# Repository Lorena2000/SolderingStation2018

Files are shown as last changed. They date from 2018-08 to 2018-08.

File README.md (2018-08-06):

# SolderingStation2018

I’m an apprentice who works in Switzerland and tried to build the soldering station. 
Unfortunatly it doesen't worked, and i had made some changes. 
I like to offer you the changes that not everyone has to find out them by themself. 

At first the Arduino pro mini with the correct pin assignment couldn’t be delivered, it
was an old version and the companies who sold them, doesn’t deliver anything to
Switzerland. So I draw a new eagle file, I just changed the Arduino mini with
an Arduino Nano. Later when everything worked I made some more changes, the
reset wasn’t connected, added a GND connection and change the connection of the
Potentiometer. 

I found the correct display for the station but the program doesn’t work on the new Arduino
version (1.8.5). But the display needs the new version to work, so I debugged
the program with help from an informatics student. 

Because I changed the Arduino and some other components I also had to change the 3D
components, but with the new version of Inventor I couldn’t import the stl.
files so I draw new ones. 

You could find the Programm, the New Stl. files, the new Arduino board with the shema and a partlist.

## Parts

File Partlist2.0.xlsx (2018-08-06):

Soldering station 2018
I'm sorry that some names are in German that's because I order them in German and wanted to be sure you found the right elements.
If you don’t understand it, just search for the articles on conrad.ch and then translate the website to English.
I just wrote where i found the articles, perhaps you found them somewere cheaper.
What | How many | Information | Where I have order it | Specificat information | Remark
Arduino Nano | 1 |  | Arduino.cc | https://store.arduino.cc/usa/arduino-nano
Potentiometer | 1 |  | conrad | Dreh Potentiometer Mono 0.25 W 10 kΩ | Artikel Nr. 9605
Switch | 1 |  | conrad | Wippschalter 12 V/DC 20 A | Artikel Nr. 700749Kfz
Power Supply | 1 |  | conrad | USB Ladegerät Goobay | Artikel Nr. 1602854 62
display | 1
OPA336U | 1 |  | Distrelec | Operationsverstärker zweifach 0.1 MHz | Artikel Nr. 30022737
78L05F | 1 |  | Distrelec | Linearer Spannungsregler 5 V SOT-89-3, | Artikel Nr. 30018604
BSN20 | 2 |  | Distrelec | Kleinleistungstransistor SOT-23 N 50 V | Artikel Nr. 17101930
IRF7416 | 1 |  | conrad | MOSFET Infineon Technologies | Artikel Nr. IRF7416PBF
Power_JACKPTH | 1 |  | conrad | Niedervolt Steckverbinder Buchse | Artikel Nr. 735742
Klinkenbuchse ø 3.5 mm | 1 |  | conrad | Klinken Steckverbinder 3.5 mm Buchse | Artikel Nr. 734101
Soldering Iron | 1 |  | conrad | Lötspitze Nadelform Weller RT1 Spitzen Größe 0.2 mm | cost ca. 50 CHF
Klinken Steckverbinder 3.5 mm Buchse | 1 |  | conrad | KlinkenSteckverbinder 3.5 mm Stecker | Artikel Nr. NYS 231
Klinken-Steckverbinder 3.5 mm Stecker | 1 |  | conrad | Klinken Steckverbinder 3.5 mm Buchse | Artikel Nr. 595223
Mikrofonkabel 2 x 0.50 mm² | 3 m |  | conrad | Mikrofonkabel 2 x 0.50 mm² Schwarz LappKabel | Artikel Nr. 49900153
Resistor | 1 | 1MΩ | This was available in a intern lager at the company I worked for. | Form of structur 0603
Resistor | 10 | 1kΩ | " | "
Resistor | 1 | 100Ω | " | "
Resistor | 3 | 10kΩ | " | "
Resistor | 1 | 56kΩ | " | "
capacitor | 5 | 100nF | " | "
capacitor | 1 | 10µF 6V | " | "
capacitor | 1 | 10µF 16V | " | "
 |  |  | Written by Lorena Lötscher

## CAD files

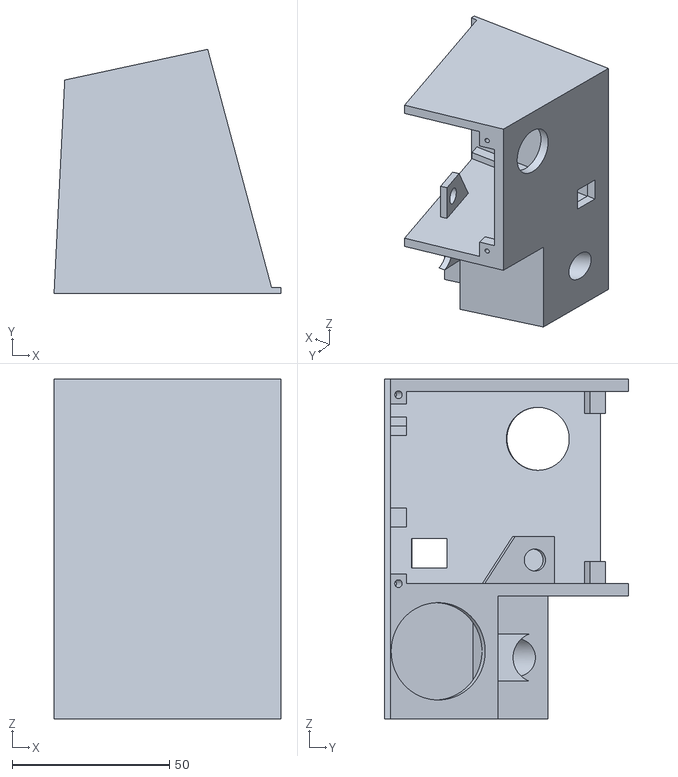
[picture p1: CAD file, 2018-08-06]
3D-Elements/stl-files/SolderingStation.stl
72.1 x 77.6 x 108.0

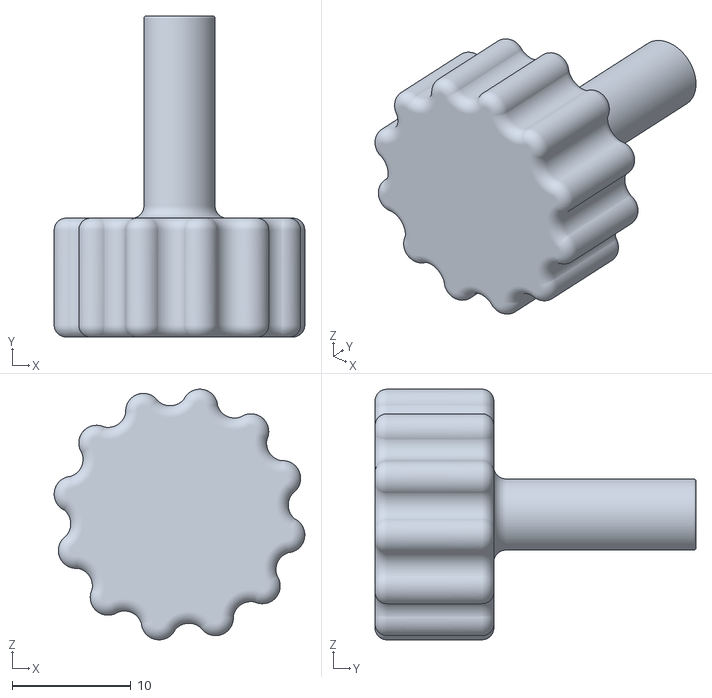
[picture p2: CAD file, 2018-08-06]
3D-Elements/stl-files/Botton.stl
21.1 x 27.0 x 21.1

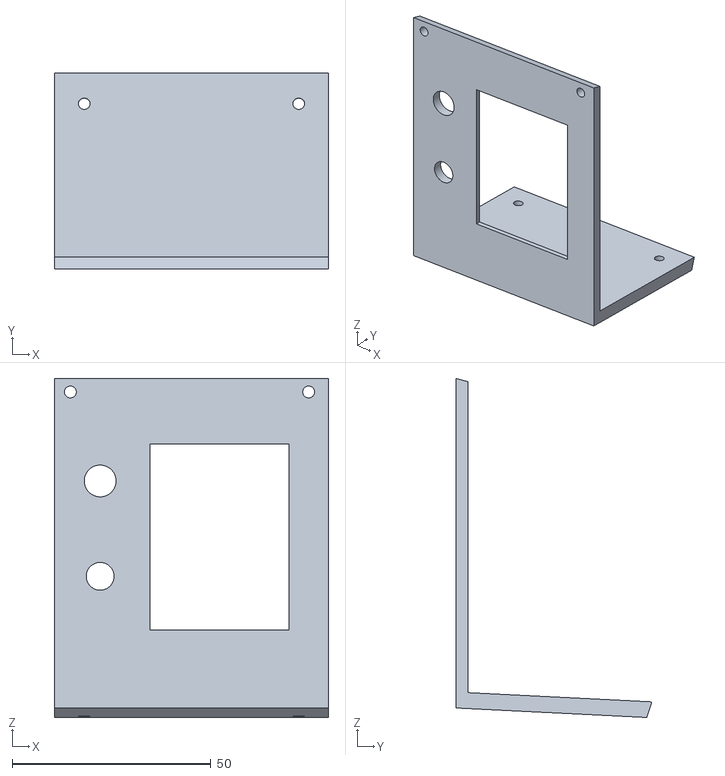
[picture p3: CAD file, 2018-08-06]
3D-Elements/stl-files/Top.stl
69.0 x 49.3 x 85.4

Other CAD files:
3D-Elements/Button.ipt
3D-Elements/SolderingStation.iam
3D-Elements/SolderingStation.ipt
3D-Elements/Top.ipt

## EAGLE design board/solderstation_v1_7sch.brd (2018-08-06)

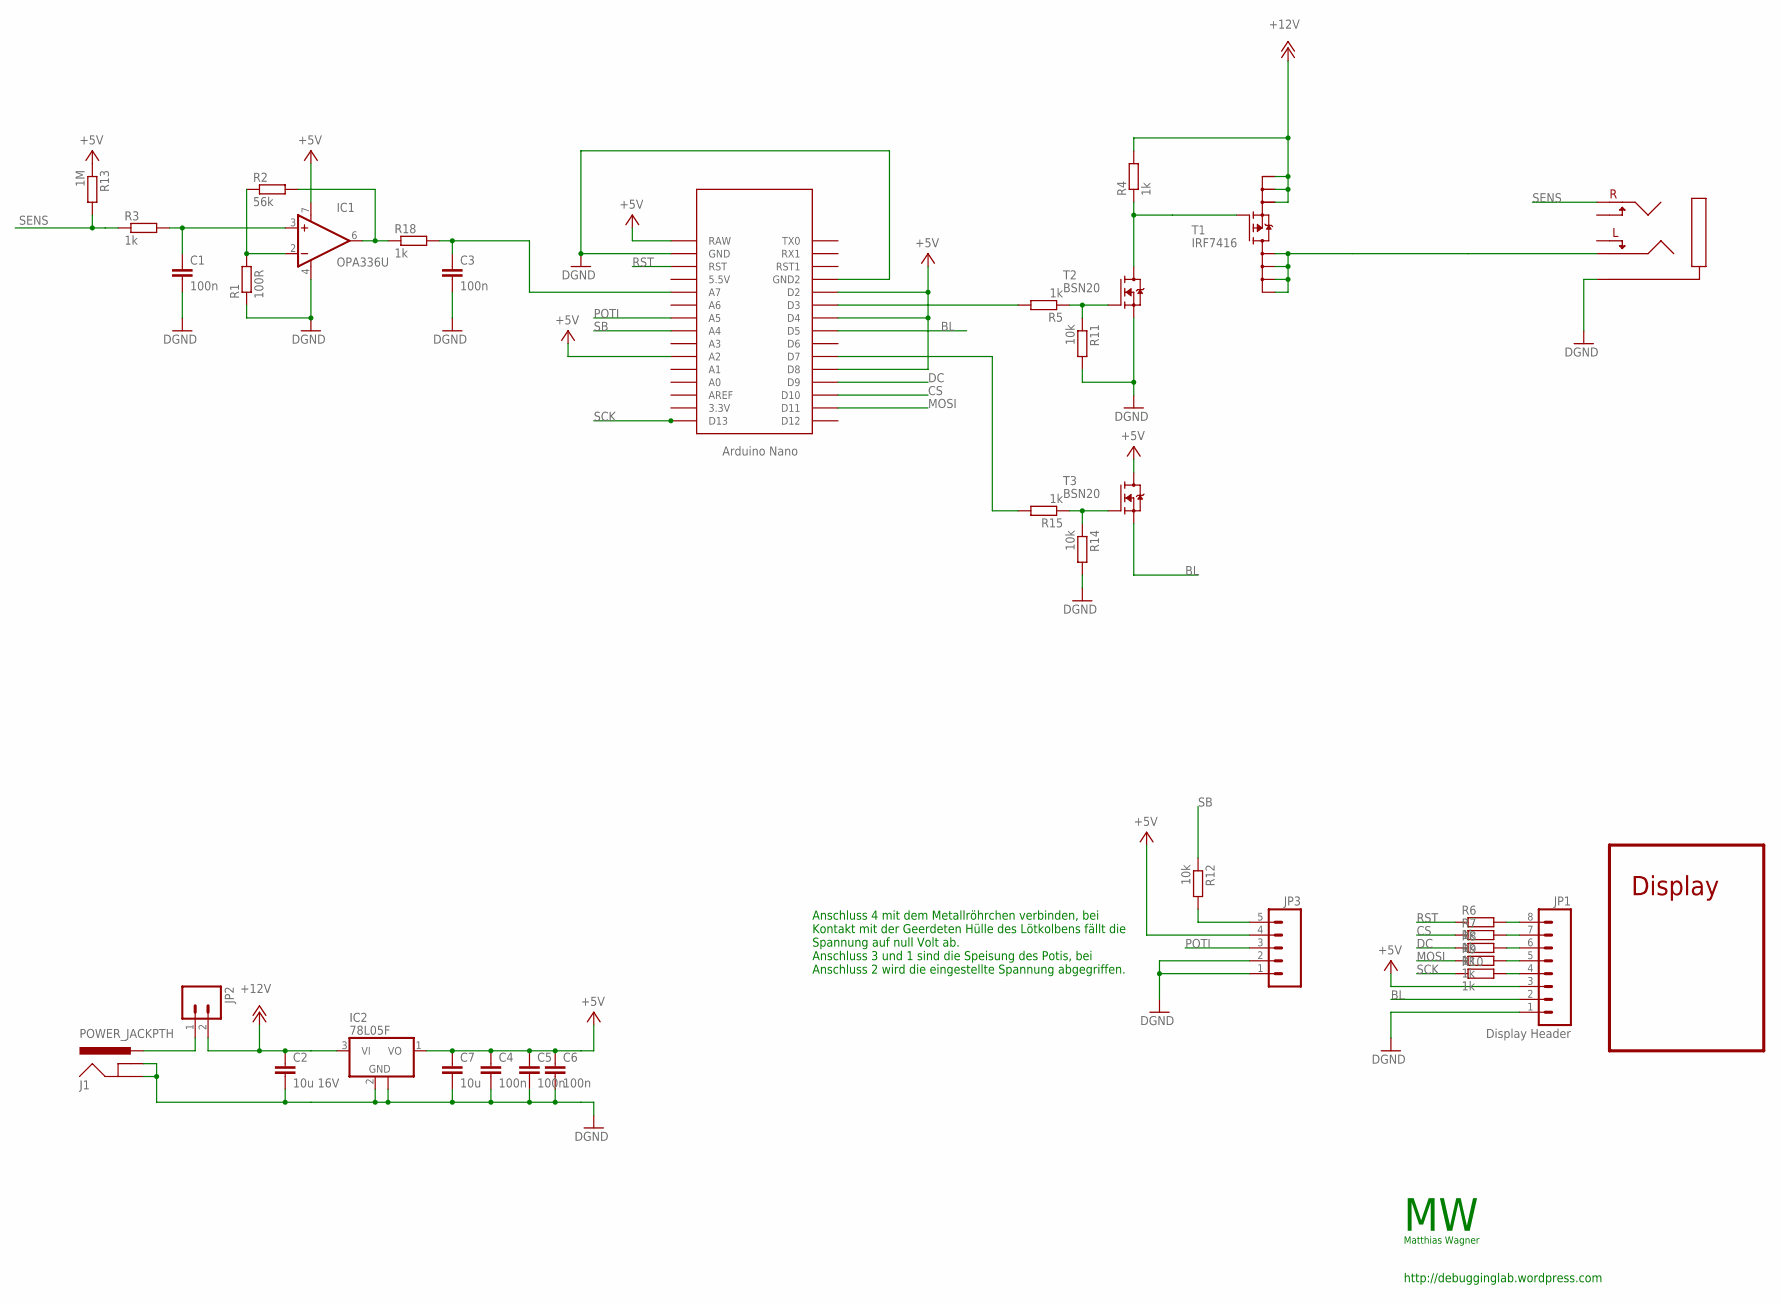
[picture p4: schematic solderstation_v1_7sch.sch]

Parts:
C1, C3, C4, C5, C6: 100n; C0603
C2: 10u 16V; C1206
C7: 10u; C1206
IC1: OPA336U; SO08
IC2: 78L05F; SOT89
J1: POWER_JACKPTH; POWER_JACK_PTH
JP1: Display Header; 1X08_LOCK
JP2: M02LOCK_LONGPADS; 1X02_LOCK_LONGPADS
JP3: M05; 05P
R1: 100R; R0603
R2: 56k; R0603
R3, R4, R5, R6, R7, R8, R9, R10, R15, R18: 1k; R0603
R11, R12, R14: 10k; R0603
R13: 1M; R0603
T1: IRF7416; SO8
T2, T3: BSN20; SOT23
U$1: NANO
U$2: AUDIO_JACK_3,5MMCONRAD; AUDIO_JACK_3,5MM_CONRAD

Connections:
+5V: C4.1, C5.1, C6.1, C7.1, IC1.7 (V+), IC2.1 (VO), JP1.3, JP3.4, R13.1, T3.3 (D), U$1.A2, U$1.D2, U$1.D4, U$1.D8, U$1.RAW
+12V: C2.1, IC2.3 (VI), JP2.2, R4.2, T1.1 (S0), T1.2 (S1), T1.3 (S2)
BL: JP1.2, T3.2 (S), U$1.D5
CS: R7.1, U$1.D10
DC: R8.1, U$1.D9
DGND: C1.2, C2.2, C3.2, C4.2, C5.2, C6.2, C7.2, IC1.4 (V-), IC2.2 (GND), IC2.2@1 (GND), J1.GND, J1.GNDBREAK, JP1.1, JP3.1, JP3.2, R1.1, R11.2, R14.2, T2.2 (S), U$1.GND, U$1.GND1 (GND2), U$2.P_GND
HEATER: T1.5 (D0), T1.6 (D1), T1.7 (D2), T1.8 (D3), U$2.P_LEFT
MOSI: R9.1, U$1.D11
unnamed: IC1.2 (-IN), R1.2, R2.1
unnamed: IC1.6 (OUT), R2.2, R18.1
unnamed: R5.1, R11.1, T2.1 (G)
unnamed: C1.1, IC1.3 (+IN), R3.2
unnamed: R4.1, T1.4 (G), T2.3 (D)
unnamed: JP1.4, R10.2
unnamed: R5.2, U$1.D3
unnamed: JP1.5, R9.2
unnamed: JP1.6, R8.2
unnamed: JP1.7, R7.2
unnamed: JP1.8, R6.2
unnamed: J1.PWR, JP2.1
unnamed: R14.1, R15.1, T3.1 (G)
unnamed: R15.2, U$1.D7
unnamed: JP3.5, R12.2
unnamed: C3.1, R18.2, U$1.A7
POTI: JP3.3, U$1.A5
RST: R6.1, U$1.RST
SB: R12.1, U$1.A4
SCK: R10.1, U$1.D13
SENS: R3.1, R13.2, U$2.P_RIGHT

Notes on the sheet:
Display
http://debugginglab.wordpress.com
Matthias Wagner
Anschluss 4 mit dem Metallröhrchen verbinden, bei Kontakt mit der Geerdeten Hülle des Lötkolbens fällt die Spannung auf null Volt ab. Anschluss 3 und 1 sind die Speisung des Potis, bei Anschluss 2 wird die eingestellte Spannung abgegriffen.

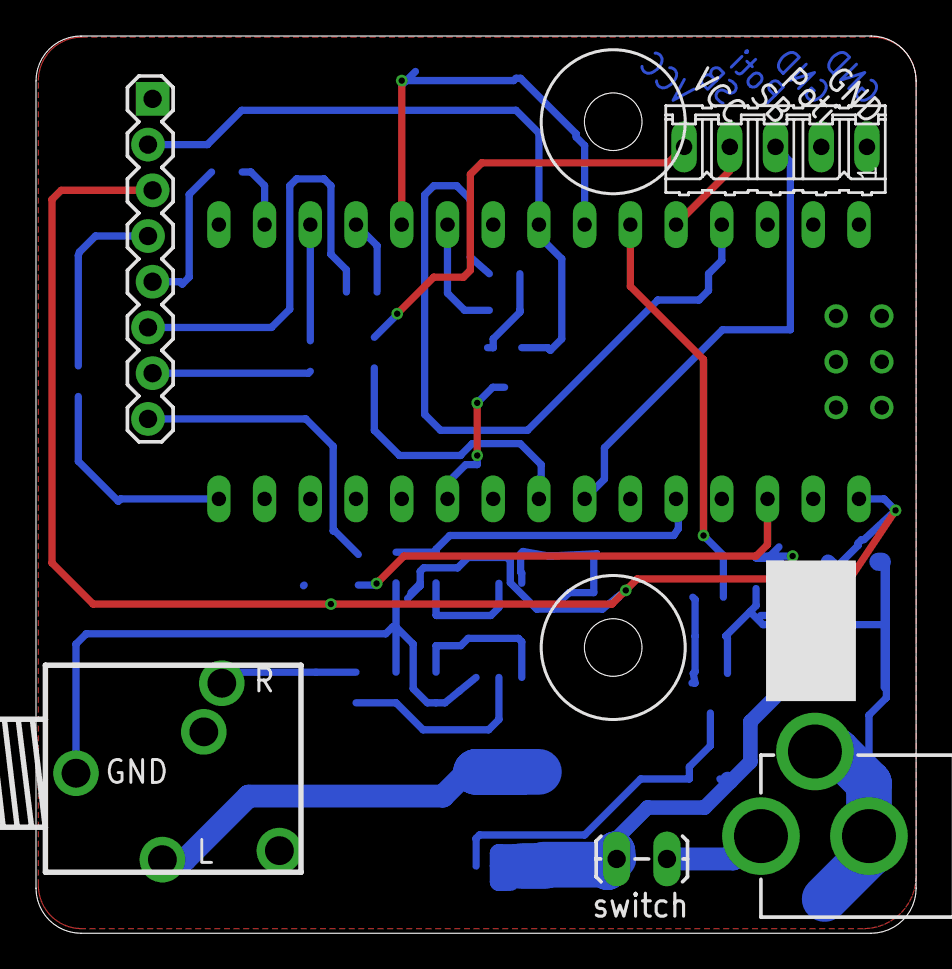
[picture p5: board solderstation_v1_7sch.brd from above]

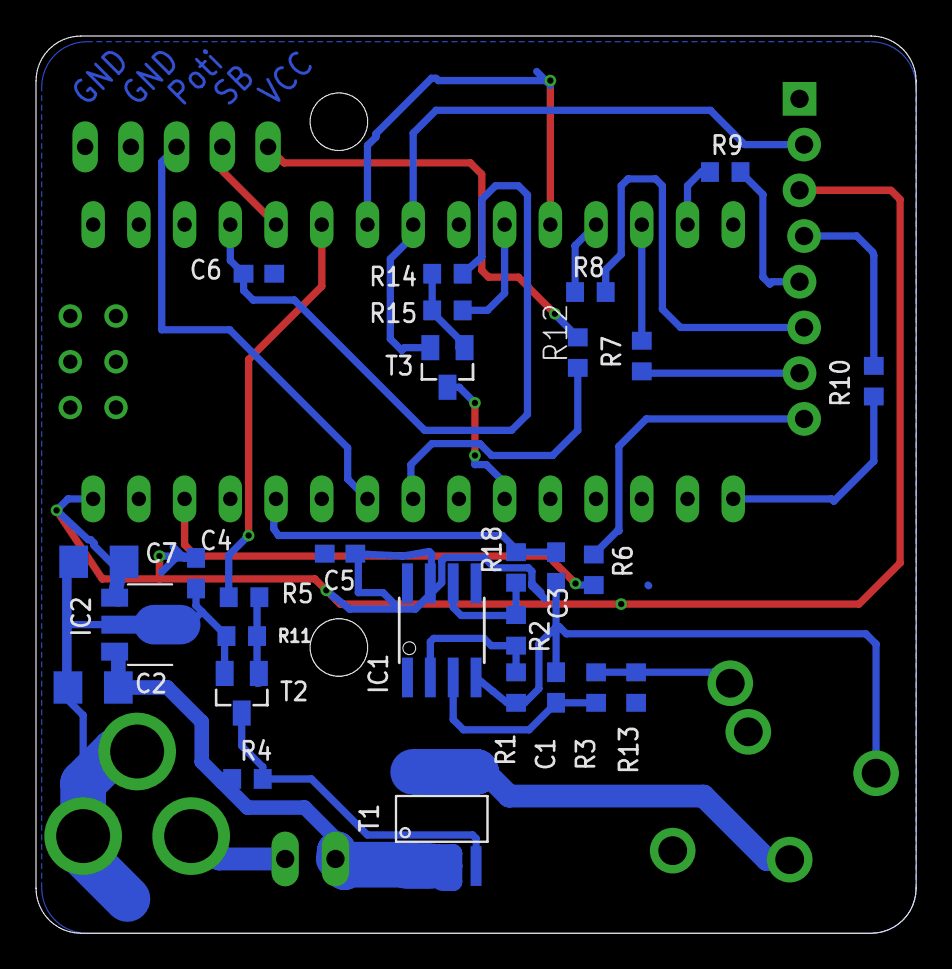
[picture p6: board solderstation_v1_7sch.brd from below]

Board: 2 copper layers, 48.9 x 49.8 mm, 34 parts (28 on the bottom side), 29 nets.

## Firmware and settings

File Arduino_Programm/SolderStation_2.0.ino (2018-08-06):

//*******************************//
// Soldering Station
// Matthias Wagner
// www.k-pank.de/so
// Get.A.Soldering.Station@gmail.com
//*******************************//

#include <Adafruit_GFX.h>    // Core graphics library
#include <Adafruit_ST7735.h> // Library for the display
#include <SPI.h>            // comunication between the Arduino and the display 

#include "iron.h"           
#include "stationLOGO.h"


#define VERSION "1.5"		//Version der Steuerung
#define INTRO

#define sclk 	13		// Don't change
#define mosi 	11		// Don't change
#define cs_tft	10		// 


//V1.5
#define dc   	9		// 8
#define rst  	12		// 9 


/*
//V1.4
#define dc   	8
#define rst  	9
*/

#define STANDBYin A4
#define POTI   	A5
#define TEMPin 	A7
#define PWMpin 	3
#define BLpin		5

#define CNTRL_GAIN 10

#define DELAY_MAIN_LOOP 	10
#define DELAY_MEASURE 		50
//#define ADC_TO_TEMP_GAIN 	0.415
#define ADC_TO_TEMP_GAIN 	0.53 //Mit original Weller Station verglichen
#define ADC_TO_TEMP_OFFSET 25.0
#define STANDBY_TEMP			175

#define BLACK     0x0000 // definite the colours of the display 
#define BLUE      0x001F
#define RED       0xF800
#define GREEN     0x07E0
#define CYAN      0x07FF
#define MAGENTA   0xF81F
#define YELLOW    0xFFE0
#define WHITE     0xFFFF
#define LightGrey   0xC618
#define DarkGrey    0x7BEF

#define OVER_SHOT 			2
#define MAX_PWM_LOW			180
#define MAX_PWM_HI			210		//254
#define MAX_POTI				400		//400Grad C

#define PWM_DIV 1024						//default: 64   31250/64 = 2ms

Adafruit_ST7735 TFTscreen = Adafruit_ST7735(cs_tft, dc, mosi, sclk, rst); // has to be compatible to the Adafruit library 

int pwm = 0; //pwm Out Val 0.. 255
int soll_temp = 300;
boolean standby_act = false;


void setup(void) {
/*
   Serial.begin(9600);
   TFTscreen.begin();
   TFTscreen.fillScreen(WHITE);
      */
	
	pinMode(BLpin, OUTPUT);
	digitalWrite(BLpin, LOW);
	
	pinMode(STANDBYin, INPUT_PULLUP);
	
	pinMode(PWMpin, OUTPUT);
	digitalWrite(PWMpin, LOW);
	setPwmFrequency(PWMpin, PWM_DIV);
	digitalWrite(PWMpin, LOW);
	
	//TFTscreen.init();
	SPI.setClockDivider(SPI_CLOCK_DIV4);  // 4MHz

  TFTscreen.initR(INITR_BLACKTAB);
	
	TFTscreen.setRotation(0);	// 0 - Portrait, 1 - Lanscape
	TFTscreen.fillScreen(BLACK);
	TFTscreen.setTextWrap(true);
	
	
	
	//Print station Logo
	TFTscreen.drawBitmap(2,1,stationLOGO1,124,47,LightGrey);
	
	TFTscreen.drawBitmap(3,3,stationLOGO1,124,47,YELLOW);		
	TFTscreen.drawBitmap(3,3,stationLOGO2,124,47,Color565(254,147,52));	
	TFTscreen.drawBitmap(3,3,stationLOGO3,124,47,Color565(255,78,0));
 
	
	//BAcklight on
	digitalWrite(BLpin, HIGH);
	
	
#if defined(INTRO)
	
	delay(500);
	
	//Print Iron
	TFTscreen.drawBitmap(15,50,iron,100,106,LightGrey);
	TFTscreen.drawBitmap(17,52,iron,100,106,YELLOW);
	delay(500);
	
	TFTscreen.setTextSize(2);
	TFTscreen.setTextColor(LightGrey);
	TFTscreen.setCursor(70,130);
	TFTscreen.print(VERSION);
	
	TFTscreen.setTextSize(2);
	TFTscreen.setTextColor(YELLOW);
	TFTscreen.setCursor(72,132);
	TFTscreen.print(VERSION);
	
	TFTscreen.setTextSize(1);
	TFTscreen.setTextColor(LightGrey);
	TFTscreen.setCursor(103,0);
	TFTscreen.print("v");
	TFTscreen.print(VERSION);
	
	TFTscreen.setTextColor(YELLOW);
	TFTscreen.setCursor(104,1);
	TFTscreen.print("v");
	TFTscreen.print(VERSION);
	
	delay(2500);
#endif
	
	
	TFTscreen.fillRect(0,47,128,125,BLACK);
	TFTscreen.setTextColor(WHITE);

	TFTscreen.setTextSize(1);
	TFTscreen.setCursor(1,84);
	TFTscreen.print("ist");
	
	TFTscreen.setTextSize(2);
	TFTscreen.setCursor(117,47);
	TFTscreen.print("o");
	
	TFTscreen.setTextSize(1);
	TFTscreen.setCursor(1,129);
	TFTscreen.print("soll");
	
	TFTscreen.setTextSize(2);
	TFTscreen.setCursor(117,92);
	TFTscreen.print("o");
	
	TFTscreen.setCursor(80,144);
	TFTscreen.print("   %");
	
	TFTscreen.setTextSize(1);
	TFTscreen.setCursor(1,151);		//60
	TFTscreen.print("pwm");
	
	TFTscreen.setTextSize(2);
	
}

void loop() {
	
	int actual_temperature = getTemperature();
	soll_temp = map(analogRead(POTI), 0, 1024, 0, MAX_POTI);
	
	
	//TODO: Put in Funktion
	TFTscreen.setCursor(2,55);
	if (digitalRead(STANDBYin) == true)
		TFTscreen.setTextColor(BLACK);
	else
		TFTscreen.setTextColor(WHITE);
	TFTscreen.print("SB");
	
	//
	
	int soll_temp_tmp = soll_temp;
	
	if (digitalRead(STANDBYin) == false)
		standby_act = true;
	else
		standby_act = false;
	
	if (standby_act && (soll_temp >= STANDBY_TEMP ))
		soll_temp_tmp = STANDBY_TEMP;
	
	
	
	int diff = (soll_temp_tmp + OVER_SHOT)- actual_temperature;
	pwm = diff*CNTRL_GAIN;
	
	int MAX_PWM;

	//Set max heating Power 
	MAX_PWM = actual_temperature <= STANDBY_TEMP ? MAX_PWM_LOW : MAX_PWM_HI;
	
	//8 Bit Range
	pwm = pwm > MAX_PWM ? pwm = MAX_PWM : pwm < 0 ? pwm = 0 : pwm;
	
	
	
	//NOTfall sicherheit / Spitze nicht eingesteckt
	if (actual_temperature > 550){
		pwm = 0;
		actual_temperature = 0;
	}
	
	
	analogWrite(PWMpin, pwm);
	//digitalWrite(PWMpin, LOW);
	
	writeHEATING(soll_temp, actual_temperature, pwm);
	
	delay(DELAY_MAIN_LOOP);		//wait for some time
}


int getTemperature()
{
  analogWrite(PWMpin, 0);		//switch off heater
  delay(DELAY_MEASURE);			//wait for some time (to get low pass filter in steady state)
  int adcValue = analogRead(TEMPin); // read the input on analog pin 7:
  Serial.print("ADC Value ");
  Serial.print(adcValue);
  analogWrite(PWMpin, pwm);	//switch heater back to last value
  return round(((float) adcValue)*ADC_TO_TEMP_GAIN+ADC_TO_TEMP_OFFSET); //apply linear conversion to actual temperature
}





void writeHEATING(int tempSOLL, int tempVAL, int pwmVAL){
	static int d_tempSOLL = 2;		//Tiefpass für Anzeige (Poti zittern)

	static int tempSOLL_OLD = 	10;
	static int tempVAL_OLD	= 	10;
	static int pwmVAL_OLD	= 	10;
	//TFT Anzeige
	
	pwmVAL = map(pwmVAL, 0, 254, 0, 100);
	
	TFTscreen.setTextSize(5);
	if (tempVAL_OLD != tempVAL){
		TFTscreen.setCursor(30,57);
		TFTscreen.setTextColor(BLACK);
		//TFTscreen.print(tempSOLL_OLD);
		//erste Stelle unterschiedlich
		if ((tempVAL_OLD/100) != (tempVAL/100)){
			TFTscreen.print(tempVAL_OLD/100);
		}
		else
			TFTscreen.print(" ");
		
		if ( ((tempVAL_OLD/10)%10) != ((tempVAL/10)%10) )
			TFTscreen.print((tempVAL_OLD/10)%10 );
		else
			TFTscreen.print(" ");
		
		if ( (tempVAL_OLD%10) != (tempVAL%10) )
			TFTscreen.print(tempVAL_OLD%10 );
		
		TFTscreen.setCursor(30,57);
		TFTscreen.setTextColor(WHITE);
		
		if (tempVAL < 100)
			TFTscreen.print(" ");
		if (tempVAL <10)
			TFTscreen.print(" ");
		
		int tempDIV = round(float(tempSOLL - tempVAL)*8.5);
		tempDIV = tempDIV > 254 ? tempDIV = 254 : tempDIV < 0 ? tempDIV = 0 : tempDIV;
		TFTscreen.setTextColor(Color565(tempDIV, 255-tempDIV, 0));
		if (standby_act)
			TFTscreen.setTextColor(CYAN);
		TFTscreen.print(tempVAL);
		
		tempVAL_OLD = tempVAL;
	}
	
	//if (tempSOLL_OLD != tempSOLL){
	if ((tempSOLL_OLD+d_tempSOLL < tempSOLL) || (tempSOLL_OLD-d_tempSOLL > tempSOLL)){
		TFTscreen.setCursor(30,102);
		TFTscreen.setTextColor(BLACK);
		//TFTscreen.print(tempSOLL_OLD);
		//erste Stelle unterschiedlich
		if ((tempSOLL_OLD/100) != (tempSOLL/100)){
			TFTscreen.print(tempSOLL_OLD/100);
		}
		else
			TFTscreen.print(" ");
		
		if ( ((tempSOLL_OLD/10)%10) != ((tempSOLL/10)%10) )
			TFTscreen.print((tempSOLL_OLD/10)%10 );
		else
			TFTscreen.print(" ");
		
		if ( (tempSOLL_OLD%10) != (tempSOLL%10) )
			TFTscreen.print(tempSOLL_OLD%10 );
		
		//Neuen Wert in Weiß schreiben
		TFTscreen.setCursor(30,102);
		TFTscreen.setTextColor(WHITE);
		if (tempSOLL < 100)
			TFTscreen.print(" ");
		if (tempSOLL <10)
			TFTscreen.print(" ");
		
		TFTscreen.print(tempSOLL);
		tempSOLL_OLD = tempSOLL;
		
	}
	
	
	TFTscreen.setTextSize(2);
	if (pwmVAL_OLD != pwmVAL){
		TFTscreen.setCursor(80,144);
		TFTscreen.setTextColor(BLACK);
		//TFTscreen.print(tempSOLL_OLD);
		//erste stelle Unterscheidlich
		if ((pwmVAL_OLD/100) != (pwmVAL/100)){
			TFTscreen.print(pwmVAL_OLD/100);
		}
		else
			TFTscreen.print(" ");
		
		if ( ((pwmVAL_OLD/10)%10) != ((pwmVAL/10)%10) )
			TFTscreen.print((pwmVAL_OLD/10)%10 );
		else
			TFTscreen.print(" ");
		
		if ( (pwmVAL_OLD%10) != (pwmVAL%10) )
			TFTscreen.print(pwmVAL_OLD%10 );
		
		TFTscreen.setCursor(80,144);
		TFTscreen.setTextColor(WHITE);
		if (pwmVAL < 100)
			TFTscreen.print(" ");
		if (pwmVAL <10)
			TFTscreen.print(" ");
		
		TFTscreen.print(pwmVAL);
		pwmVAL_OLD = pwmVAL;
		
	}
	
}




uint16_t Color565(uint8_t r, uint8_t g, uint8_t b) {
  return ((r & 0xF8) << 8) | ((g & 0xFC) << 3) | (b >> 3);
}



void setPwmFrequency(int pin, int divisor) {
  byte mode;
  if(pin == 5 || pin == 6 || pin == 9 || pin == 10) {
    switch(divisor) {
      case 1: mode = 0x01; break;
      case 8: mode = 0x02; break;
      case 64: mode = 0x03; break;
      case 256: mode = 0x04; break;
      case 1024: mode = 0x05; break;
      default: return;
    }
    if(pin == 5 || pin == 6) {
      TCCR0B = TCCR0B & 0b11111000 | mode;
    } else {
      TCCR1B = TCCR1B & 0b11111000 | mode;
    }
  } else if(pin == 3 || pin == 11) {
    switch(divisor) {
      case 1: mode = 0x01; break;
      case 8: mode = 0x02; break;
      case 32: mode = 0x03; break;
      case 64: mode = 0x04; break;
      case 128: mode = 0x05; break;
      case 256: mode = 0x06; break;
      case 1024: mode = 0x7; break;
      default: return;
    }
    TCCR2B = TCCR2B & 0b11111000 | mode;
  }
}

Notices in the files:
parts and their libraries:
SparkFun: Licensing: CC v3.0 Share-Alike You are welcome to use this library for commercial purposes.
